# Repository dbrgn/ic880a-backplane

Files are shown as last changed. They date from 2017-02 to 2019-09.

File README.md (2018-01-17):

# iC880A + Raspberry Pi Backplane

*Buy this board at [shop.coredump.ch](https://shop.coredump.ch/product/ic880a-lorawan-gateway-backplane/)!*

This is a backplane to connect an iC880A-SPI concentrator board to a Raspberry
Pi. It is inspired by the [iC880A backplane by
@gonzalocasas](https://github.com/gonzalocasas/ic880a-backplane), but aims to
give you the following additional features:

Power

- Screw terminal and footprint for MP1584 step-down regulator module (6.7-28V)
- Screw terminal for direct power input/output (5V)
- Protection diode and resettable polyfuse against high voltage spikes
- Protection against reverse polarity power input

Headers

- Full access to Raspberry Pi GPIO header
- Pin header for serial communication (RX/TX)
- 2 Pin headers for I²C based sensors (SDA/SCL/GND/3.3V/5V)

Sensors

- A [SHT21](https://sensirion.com/sht21/) temperature/humidity sensor
- An MCP3425 16-bit ADC to measure RPi supply voltage

Other

- Pin header with flyback diode for 5V fan (5V/GND)
- General purpose button connected to GPIO pin (e.g. for controlled Raspi
  shutdown)
- Three general purpose SMD LEDs (Note: Only usable from Raspi versions
  with 40-pin GPIO header)
- Mounting holes for Raspberry Pi B+ / 2B / 3B / Zero

## PCB

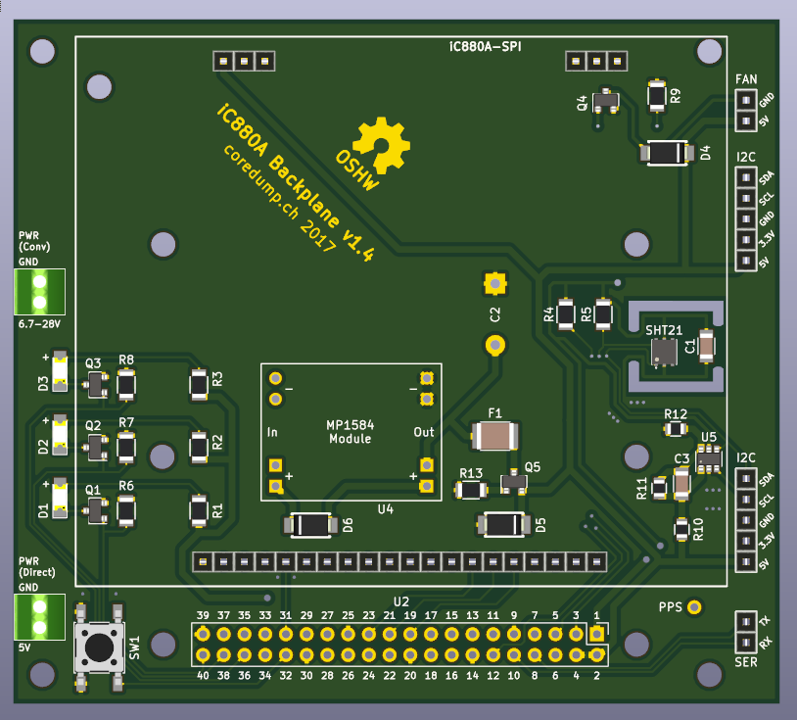
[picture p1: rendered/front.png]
Rendered


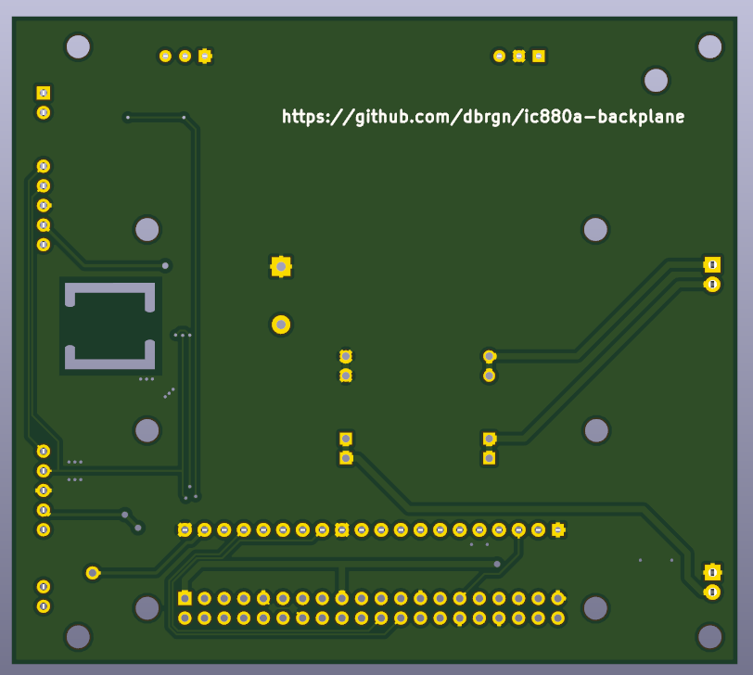
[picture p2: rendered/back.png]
Rendered


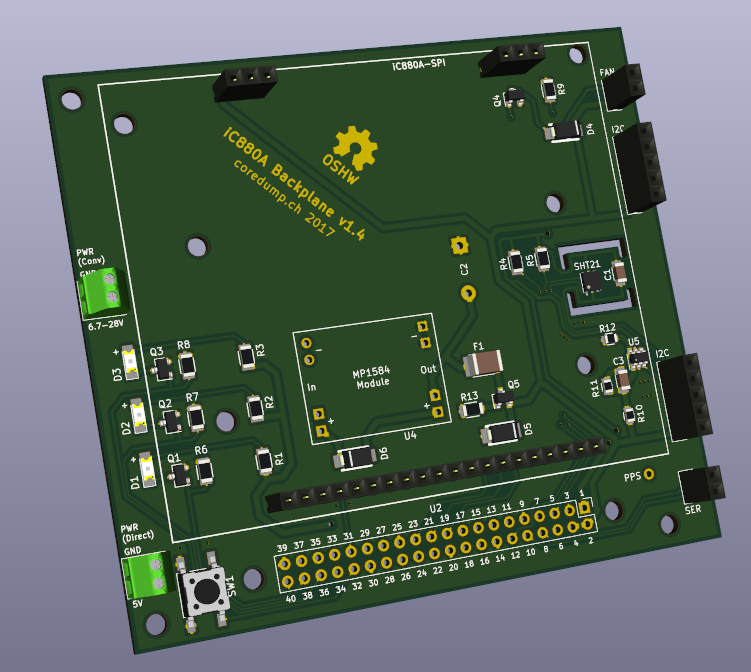
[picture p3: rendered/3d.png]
Rendered


## Schematics

See [schematics-v1.4.pdf](schematics-v1.4.pdf).

## Development

This PCB was created using KiCad 4.

Make sure that you clone all submodules:

    git submodule init
    git submodule update

## License

© 2017–2018 Danilo Bargen. Licensed under the TAPR Open Hardware License (www.tapr.org/OHL).

If you make any modification to this board, it would be great if you could let
me know at mail@dbrgn.ch.

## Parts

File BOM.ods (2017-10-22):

BOM as of v1.4, 2017-10-22
 | Description | Count | Manufacturer | Value | Case | digikey.com | mikroshop.ch
Main | iC880A-SPI | 1 | IMST
 | Raspberry Pi | 1
 | Backplane PCB | 1
 | 2 Pin Screw Terminal Block 2.54mm | 1 |  |  |  |  | 9_410
 | Pin Header 1x2 | 2
 | Pin Header 1x3 | 2
 | Pin Header 1x5 | 2
 | Pin Header 1x20 | 1
 | Resettable Fuse | 1 | Bourns |  |  | MF-MSMF250/16X-2CT-ND
 | Protection Diode | 1 | Vishay |  |  | SMBJ5.0A-E3/5BGICT-ND
 | Protection MOSFET P-Channel | 1 | Diodes Incorporated |  |  | DMG2305UX-13DICT-ND
 | Resistor | 1 | Yageo | 10kΩ | 1206 | 311-10KERCT-ND | 1_47_173
LEDs | MOSFET N-Channel | 3 | Toshiba |  | SOT-23 | SSM3K329RLFCT-ND
 | Resistor | 3 | Yageo | 10kΩ | 1206 | 311-10KERCT-ND | 1_47_173
 | SMD LED R | 1 |  | 2-2.2V | 1206 |  | 7_428
 | SMD LED Y | 1 |  | 2-2.2V | 1206 |  | 7_113
 | SMD LED B | 1 |  | 3-3.2V | 1206 |  | 7_429
 | Resistor R/Y | 2 | Yageo | 82Ω | 1206 | 311-82ERCT-ND | 1_47_142
 | Resistor B | 1 | Yageo | 22Ω | 1206 | 311-22ERCT-ND | 1_47_133
Sensor | SHT21 Sensor | 1 | Sensirion |  | DNT | 1649-1005-1-ND
 | Capacitor | 1 | Samsung or Yageo | 100nF | 1206 | 1276-1017-1-ND | 2_494
 | Resistor | 2 | Yageo | 10kΩ | 1206 | 311-10KERCT-ND | 1_47_173
Regulator | MP1584 Step-Down Module | 1 |  |  |  |  | 10_1124
 | 2 Pin Screw Terminal Block 2.54mm | 1 |  |  |  |  | 9_410
Fan | MOSFET N-Channel | 1 | Toshiba |  | SOT-23 | SSM3K329RLFCT-ND
 | Schottky Diode | 1 | Vishay |  | DO214-AC |  | 8_896
 | Resistor | 1 | Yageo | 10kΩ | 1206 |  | 1_47_173
ADC | MCP3425 | 1 | Microchip |  |  | MCP3425A0T-E/CHCT-ND
 | Resistor | 1 | Yageo | 470Ω | 805 | 311-470CRCT-ND
 | Resistor | 1 | Yageo | 3.6kΩ | 805 | 311-3.60KCRCT-ND
 | Resistor | 1 | Yageo | 6.8kΩ | 805 | 311-6.80KCRCT-ND
 | Capacitor | 1 | Samsung or Yageo | 100nF | 1206 | 1276-1017-1-ND | 2_494

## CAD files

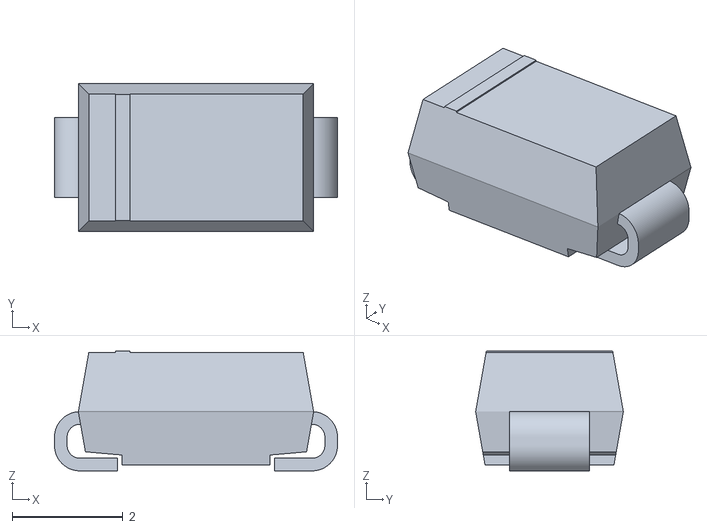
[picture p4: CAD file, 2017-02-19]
DO-214.3d/AB2_DO-214AC_WINGS3D.stl
5.11 x 2.66 x 2.16

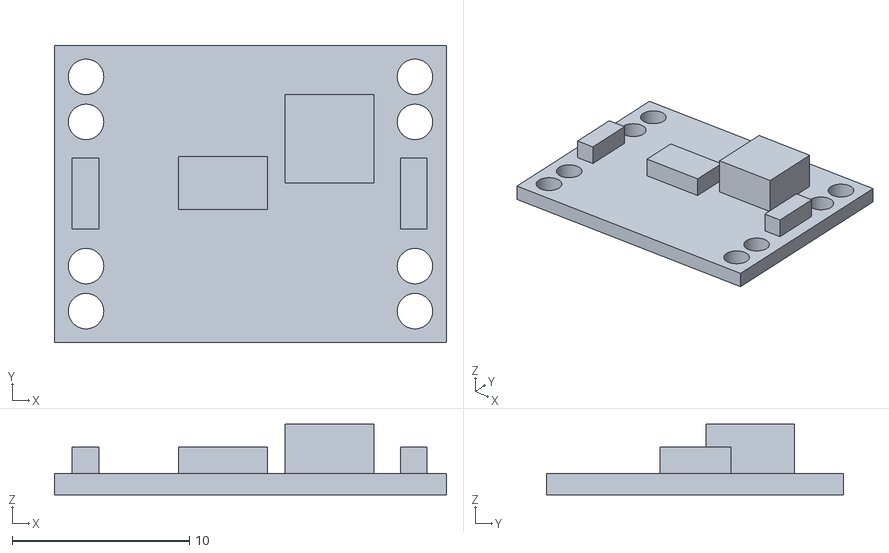
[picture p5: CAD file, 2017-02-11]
mp1584_module.stl
22.1 x 16.8 x 4.00

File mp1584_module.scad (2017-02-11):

$fn = 50;

w = 22.098;
h = 16.764;

module pin() {
    cylinder(h=2, r=1);
}

module pcb() {
    difference() {
        cube([22.098, 16.764, 1.2]);
        
        translate([1.778, 1.778]) pin();
        translate([w-1.778, 1.778]) pin();
        translate([w-1.778, h-1.778]) pin();
        translate([1.778, h-1.778]) pin();
        
        translate([1.778, 4.318]) pin();
        translate([w-1.778, 4.318]) pin();
        translate([w-1.778, h-4.318]) pin();
        translate([1.778, h-4.318]) pin();
    }
}

module parts() {
    translate([13, 9, 0])
        cube([5, 5, 2.8]);
    translate([7, 7.5, 0])
        cube([5, 3, 1.5]);
    translate([1, 6.4, 0])
        cube([1.5, 4, 1.5]);
    translate([19.5, 6.4, 0])
        cube([1.5, 4, 1.5]);
}

pcb();
translate([0, 0, 1.2]) parts();

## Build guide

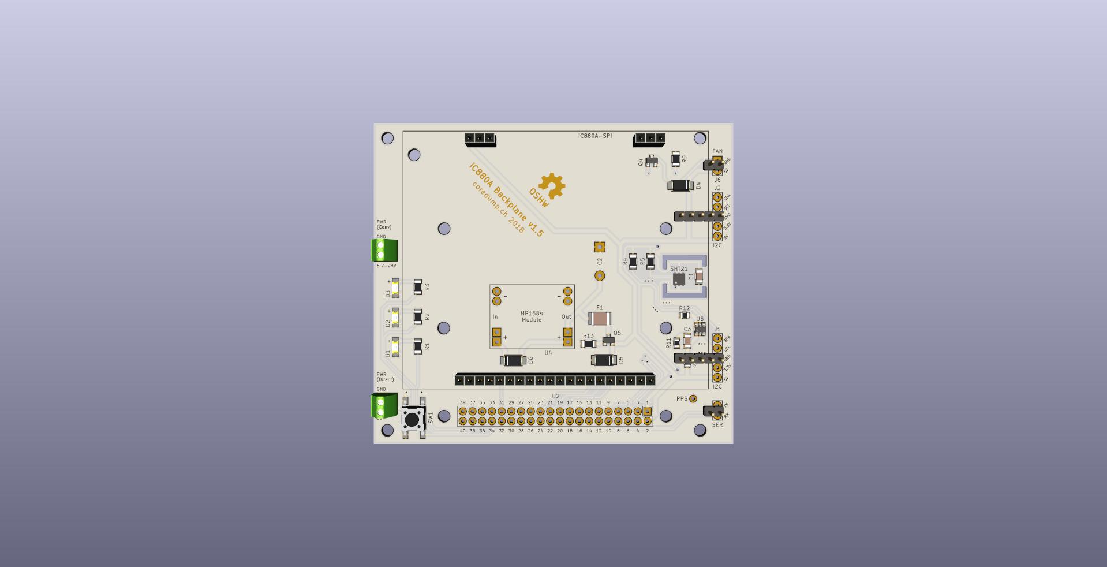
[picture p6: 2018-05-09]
backplane-assembly.jpg

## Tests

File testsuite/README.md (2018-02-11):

Testing setup moved to [dbrgn/ic880a-backplane-testimage](https://github.com/dbrgn/ic880a-backplane-testimage).

The Python test scripts are located [here](https://github.com/dbrgn/ic880a-backplane-testimage/tree/master/ic880a-backplane/rootfs-overlay/root).

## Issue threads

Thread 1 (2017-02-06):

Remove GPS header

dbrgn, 2017-02-06:
https://www.thethingsnetwork.org/forum/t/advantage-of-connecting-gps-to-gateway/1111/2

Looks like the GPS RX/TX pins are only needed to pass data from the onboard GPS to the host.

Since the board doesn't currently include GPS (to my knowledge), that is not really useful.

And since I don't know how to connect a GPS to the PPS input, it's probably better to leave the header away instead of creating a half-baked solution.

Closed 2017-02-06.

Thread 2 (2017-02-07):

More mounting holes?

dbrgn, 2017-02-07:
Is the Raspberry Pi Zero different?

I won't add the old model B mounting holes since the GPIO header isn't compatible anyways.

Closed 2017-02-08.

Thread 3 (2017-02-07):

Fix silkscreen

dbrgn, 2017-02-07:
Make sure silkscreen labels are correct everywhere.

Closed 2017-02-08.

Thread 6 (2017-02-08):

Add step-down voltage regulator

dbrgn, 2017-02-08:
Something around the range of 5-12v should be fine. Good in combination with PoE kits.

Maybe add capacitor at 5V output to stabilize voltage.

Closed 2017-02-12.

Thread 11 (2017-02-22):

Fix MOSFETs

dbrgn, 2017-02-22:
First order has wrong pin order on MOSFETs.

It's still perfectly fine though when not populating the LEDs and/or the fan. But it should be fixed for the next order. Alternative would be rotating the MOSFETs and jumper wire.

dbrgn, 2017-02-22:
https://www.digikey.com/product-detail/en/toshiba-semiconductor-and-storage/SSM3K339R,LF/SSM3K339RLFCT-ND/4781038

Closed 2017-03-14.

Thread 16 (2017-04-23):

Make sensor cutouts easier to manufacture

dbrgn, 2017-04-23:
Instead of 90° angles, use a small rounded corner so that it can be properly milled.

dbrgn, 2017-10-10:
Since it always worked out nicely so far, I don't see the need to change it.

Closed 2017-10-10.

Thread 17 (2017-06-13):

Use self locking footprints for pin headers

dbrgn, 2017-06-13:
https://www.sparkfun.com/tutorials/114

dbrgn, 2018-01-17:
Didn't work out well.

Closed 2018-01-17.

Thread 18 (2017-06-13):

Improve button footprint

dbrgn, 2017-06-13:
The pin spacing is a bit too large.

Closed 2017-06-16.

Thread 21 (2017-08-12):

Hole for attaching iC880A to board

dbrgn, 2017-08-12:
For better mechanical stability.

Closed 2017-10-10.

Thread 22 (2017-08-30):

Get rid of D5

dbrgn, 2017-08-30:
The diode is not necessary when choosing the P-FET correctly:

https://www.youtube.com/watch?v=IrB-FPcv1Dc

ubruhin, 2017-08-30:
D5 does *not* have the same functionality as the diode shown in the video. Our diode is for transient voltage suppression, not for Vgs overvoltage protection.

dbrgn, 2017-08-30:
Oops, you're right. Thanks for noting, it's a bit late :smile:

Closed 2017-08-30.

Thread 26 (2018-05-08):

Move Vin connectors out of the way

dbrgn, 2018-05-08:
It should be impossible to short with the USB/Ethernet connectors.

Closed 2018-05-10.

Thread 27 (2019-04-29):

Raspberry Pi 3B+

Wlanfr3ak, 2019-04-29:
Is it compatible to the Raspberry Pi 3B+ ?

dbrgn, 2019-04-30:
It seems that the pinout didn't change, so yes, it should be compatible :slightly_smiling_face: I didn't test it though.

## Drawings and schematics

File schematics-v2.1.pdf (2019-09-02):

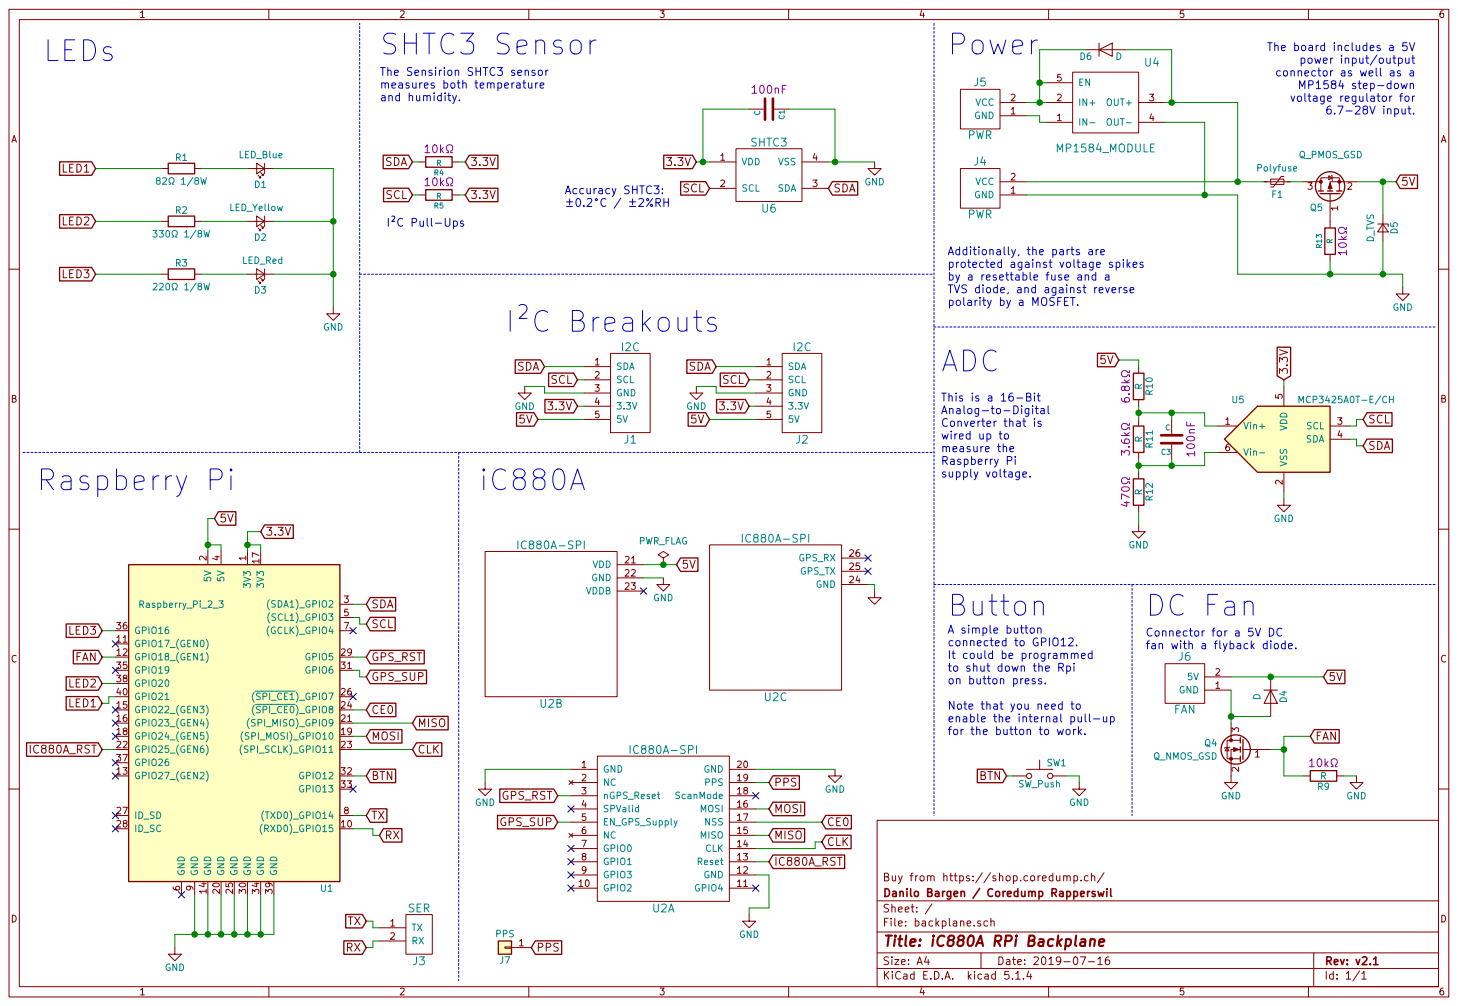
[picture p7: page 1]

power input/output connector as well as a MP1584 step-down

5 Vin- 6 U5 MCP3425A0T-E/CH GND GND GND

Additionally, the parts are
protected against voltage spikes
by a resettable fuse and a
TVS diode, and against reverse
polarity by a MOSFET.
ADC

This is a 16-Bit Analog-to-Digital

Converter that is
wired up to measure the Raspberry Pi

9U1 Raspberry_Pi_2_3 GND 1 GPIO2 10 GPIO4 11 GND 12 Reset 13 CLK 14 MISO 15 MOSI 16 NSS 17 ScanMode 18 PPS 19 NC 2 GND 20

A simple button
connected to GPIO12.
It could be programmed
to shut down the Rpi
on button press.

Connector for a 5V DC
fan with a flyback diode.

Note that you need to
enable the internal pull-up
for the button to work.

Buy from https://shop.coredump.ch/
File: backplane.sch Sheet: / Danilo Bargen / Coredump Rapperswil

Id: 1/1 Title: iC880A RPi Backplane

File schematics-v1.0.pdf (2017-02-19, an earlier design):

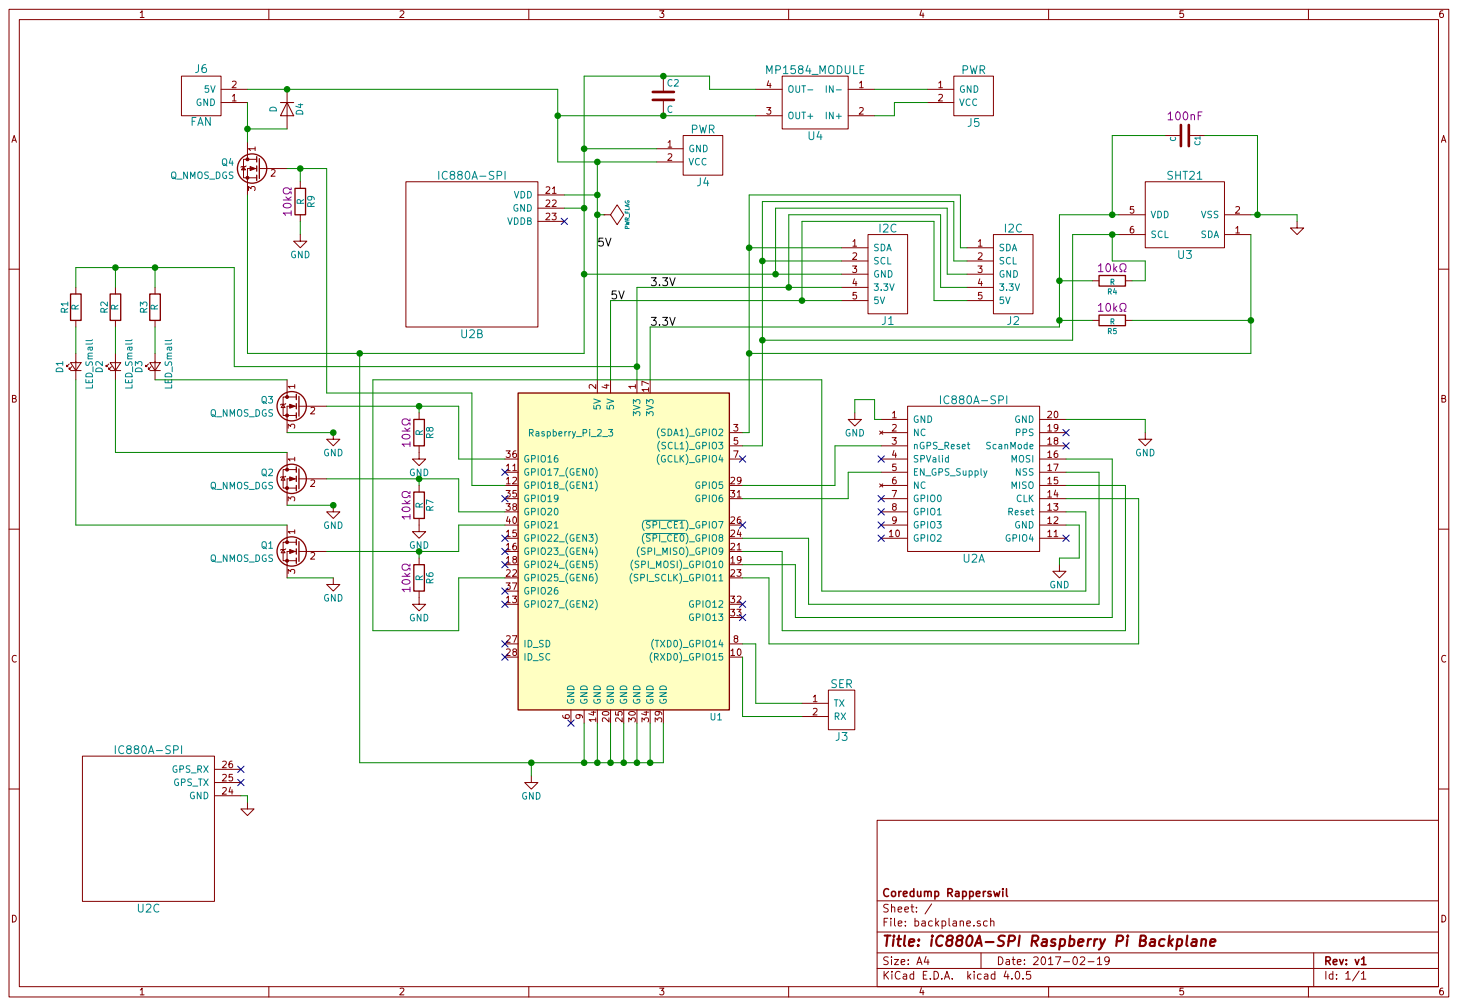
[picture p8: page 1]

3 Q1 Q_NMOS_DGS GND GND GND GND GND GND GND

File: backplane.sch Sheet: / Coredump Rapperswil

Id: 1/1 Title: iC880A-SPI Raspberry Pi Backplane

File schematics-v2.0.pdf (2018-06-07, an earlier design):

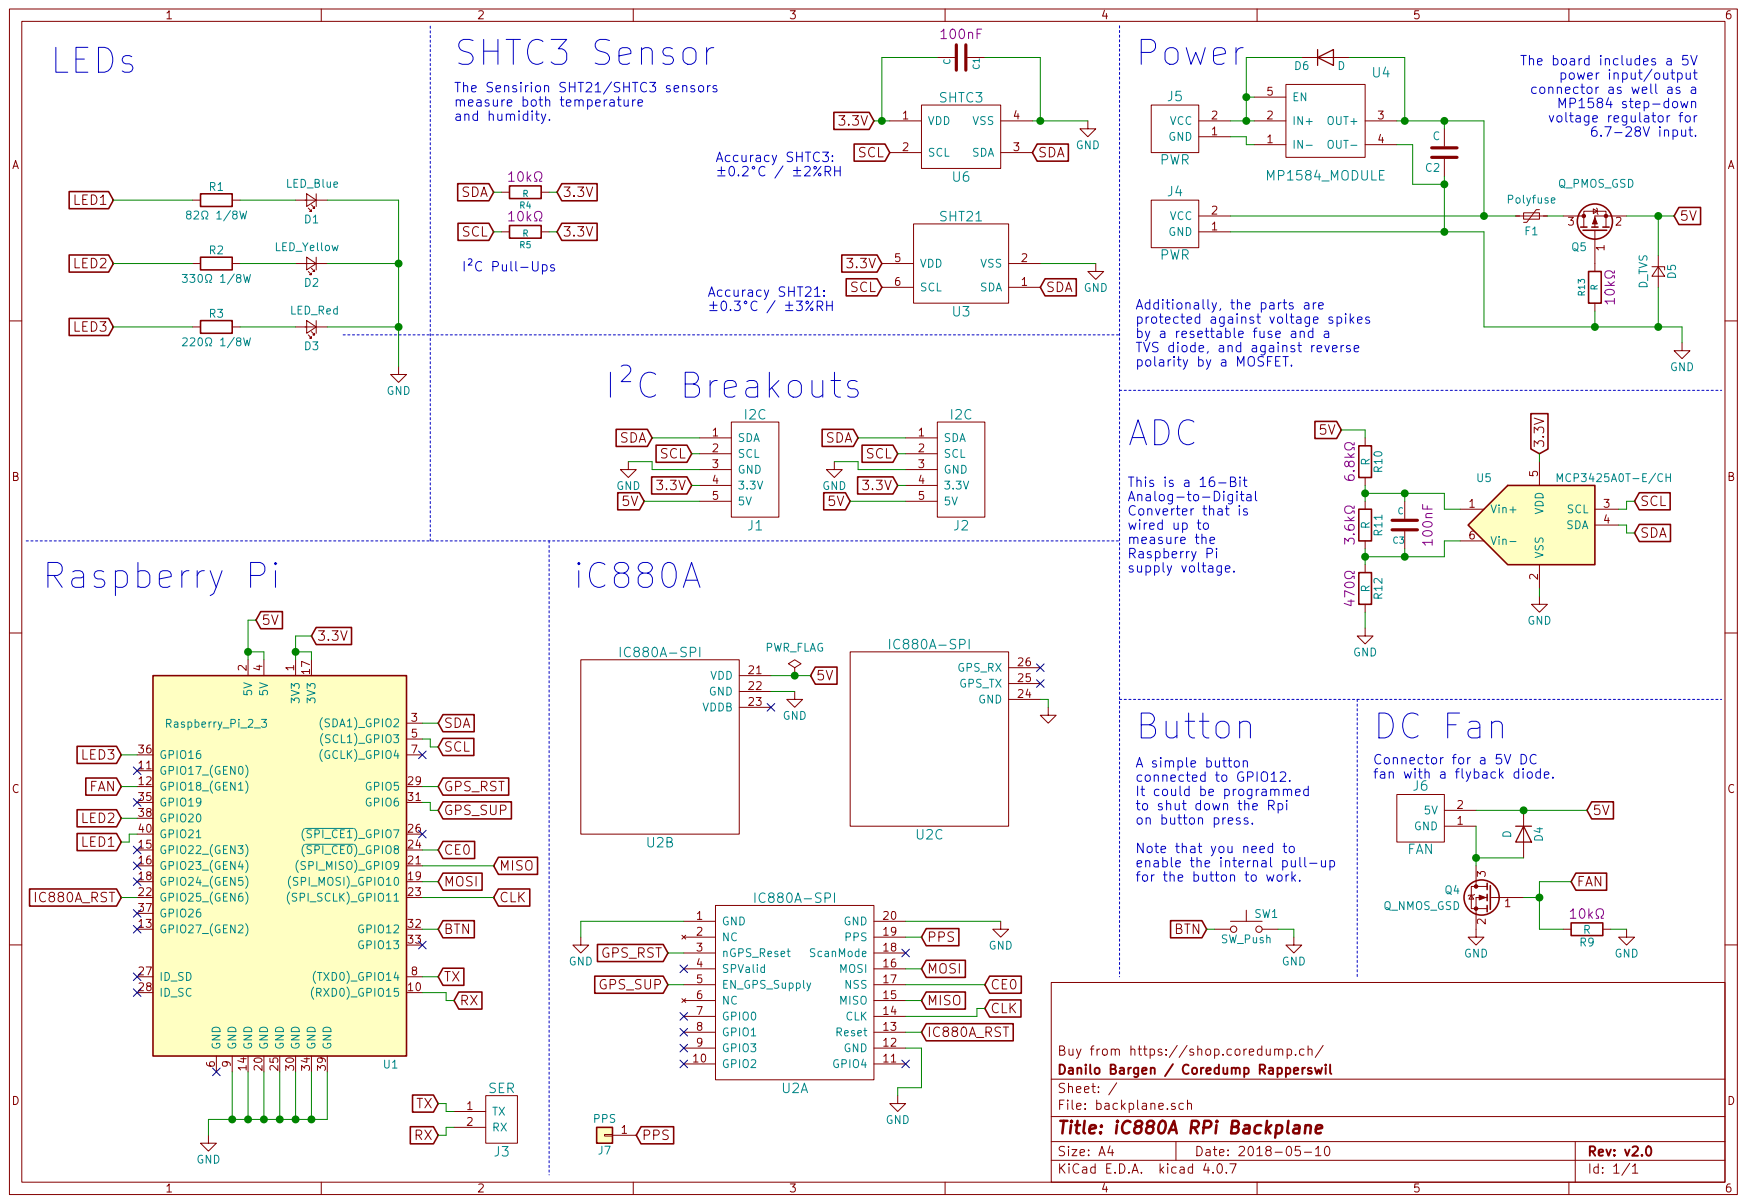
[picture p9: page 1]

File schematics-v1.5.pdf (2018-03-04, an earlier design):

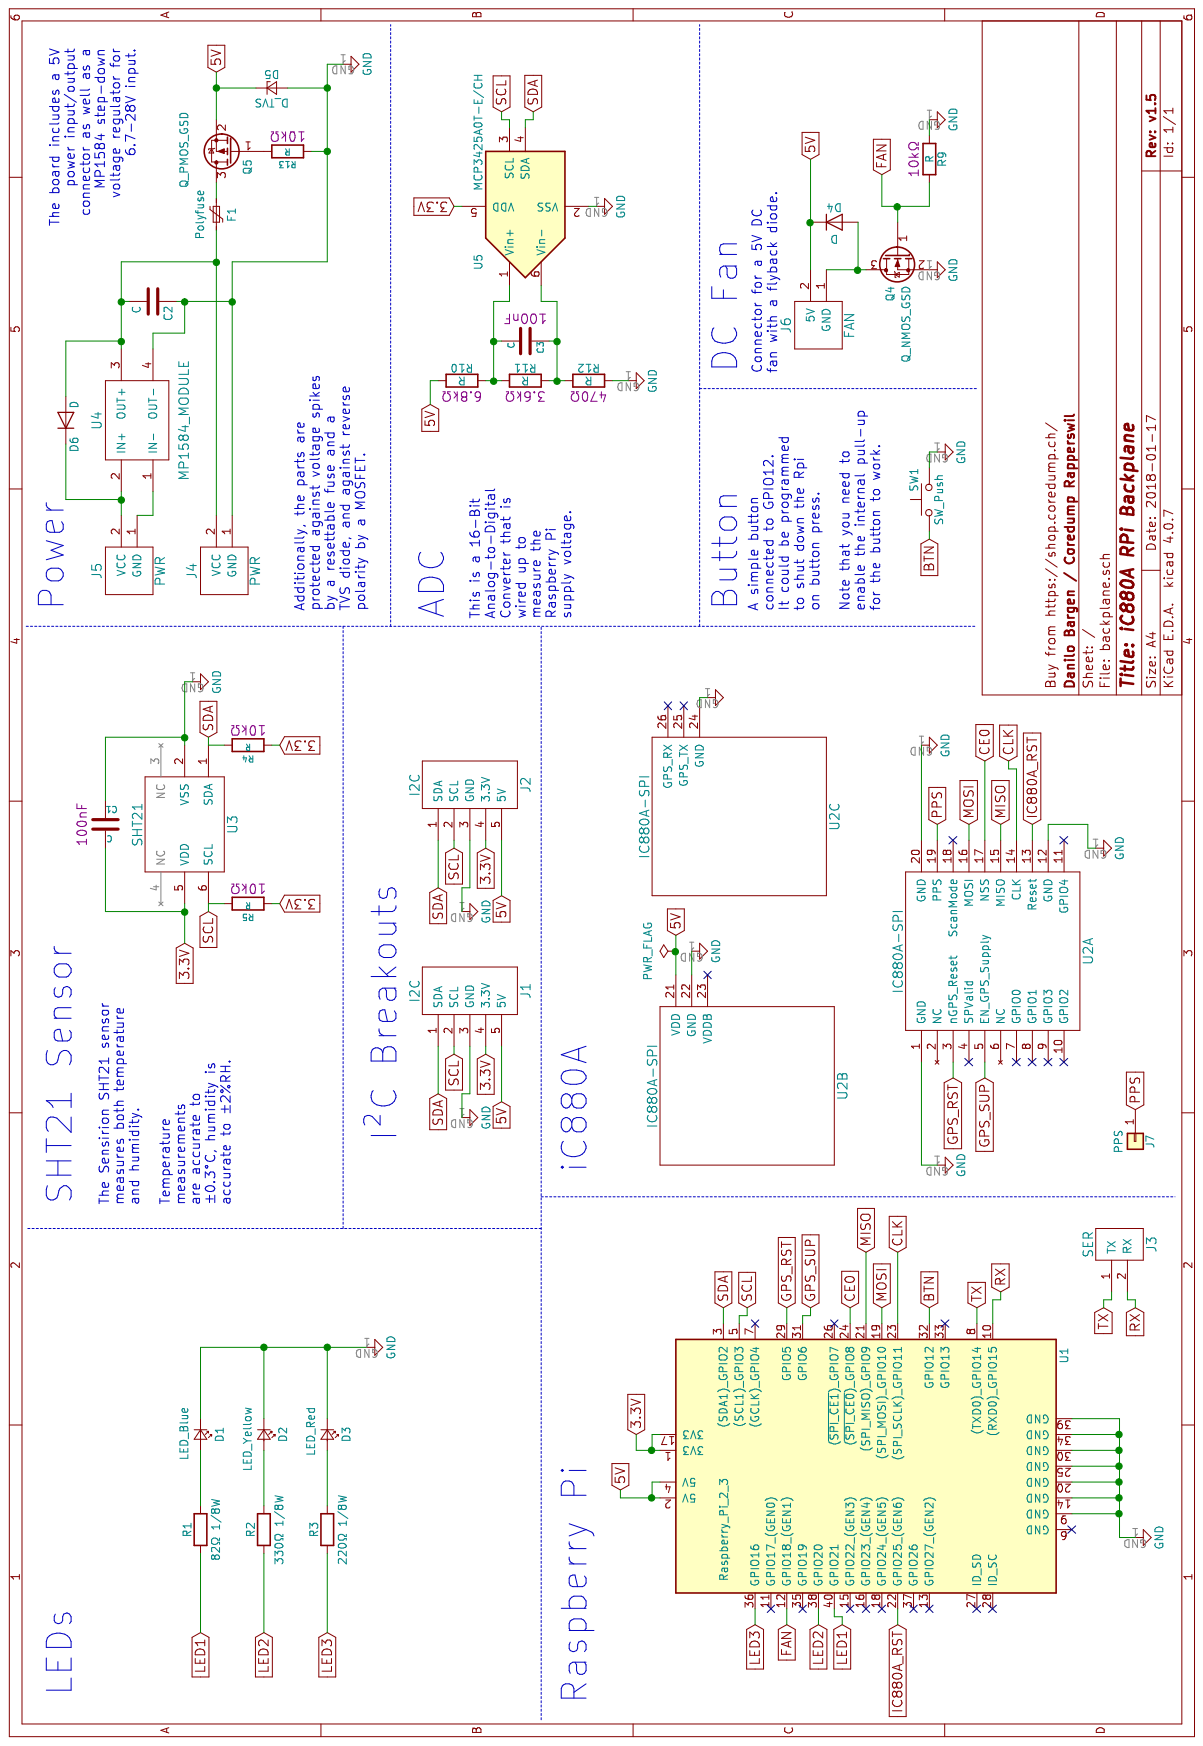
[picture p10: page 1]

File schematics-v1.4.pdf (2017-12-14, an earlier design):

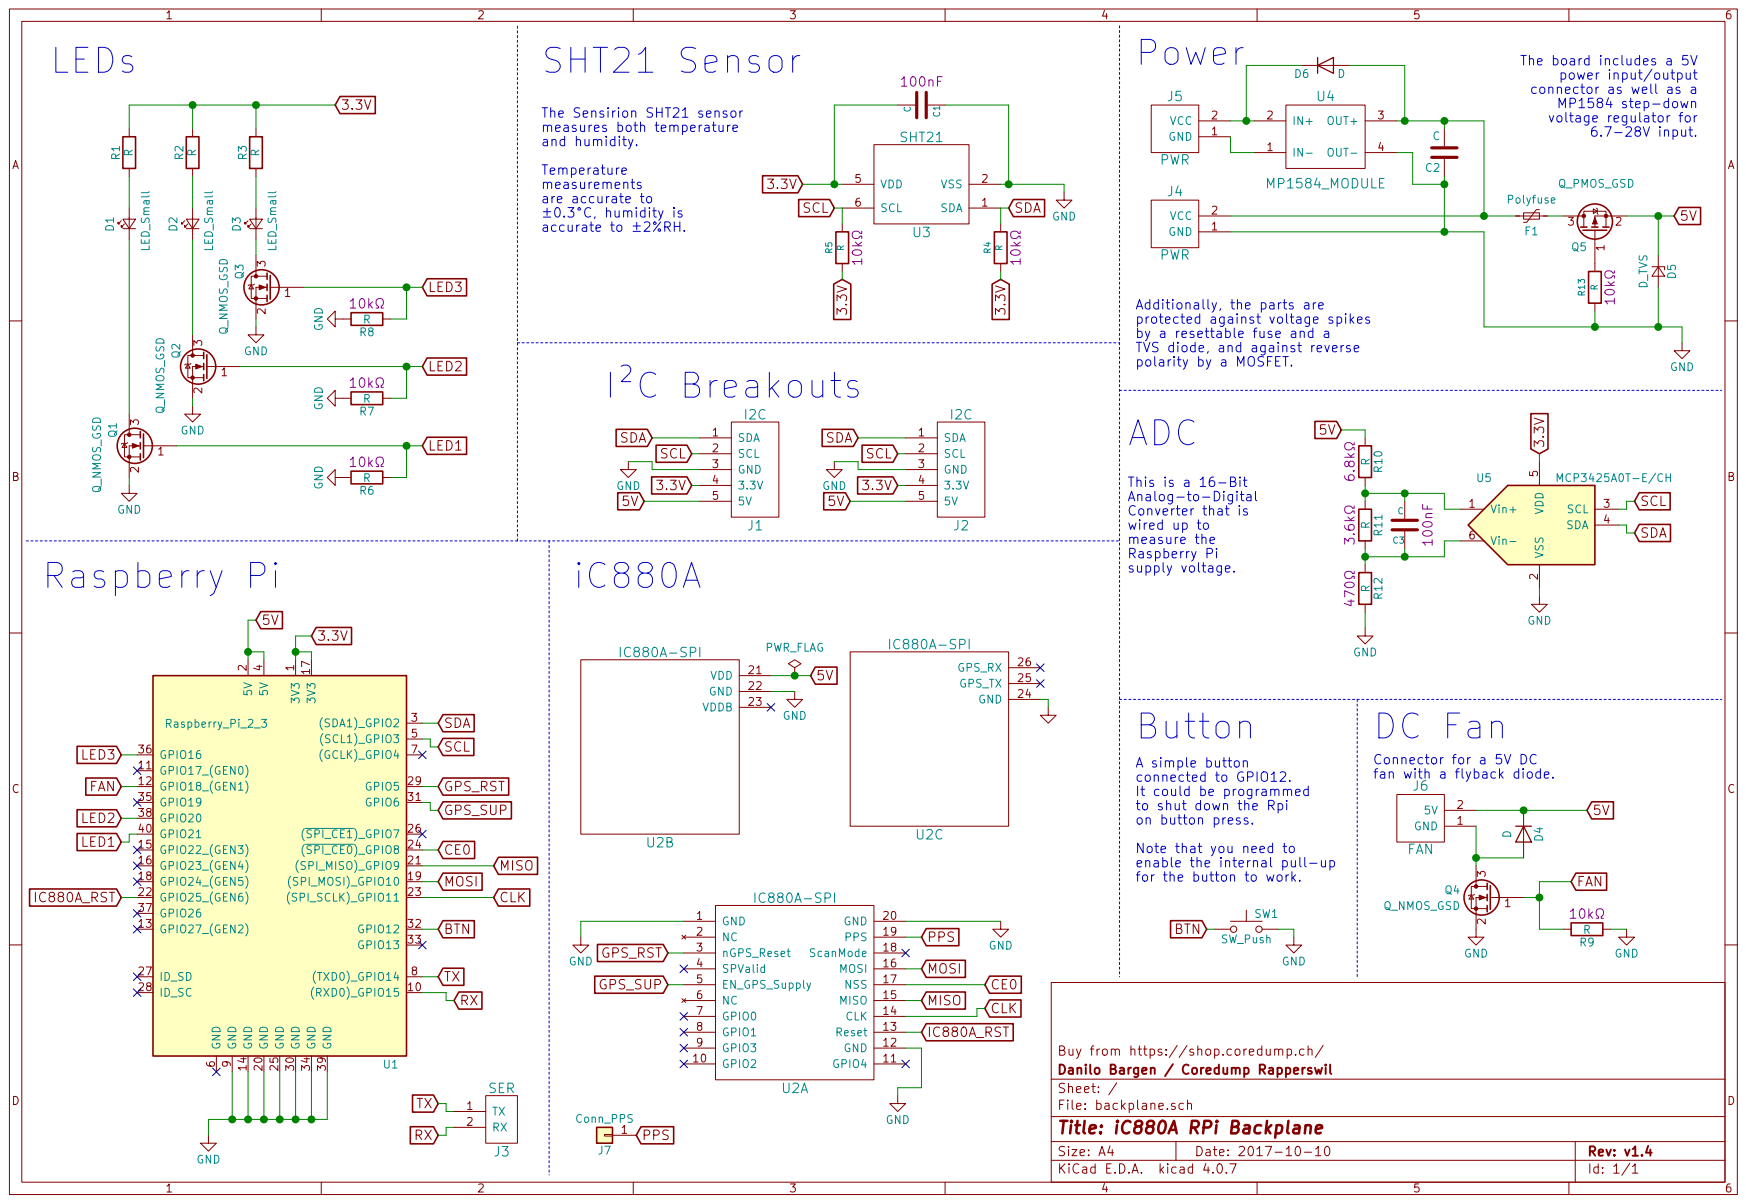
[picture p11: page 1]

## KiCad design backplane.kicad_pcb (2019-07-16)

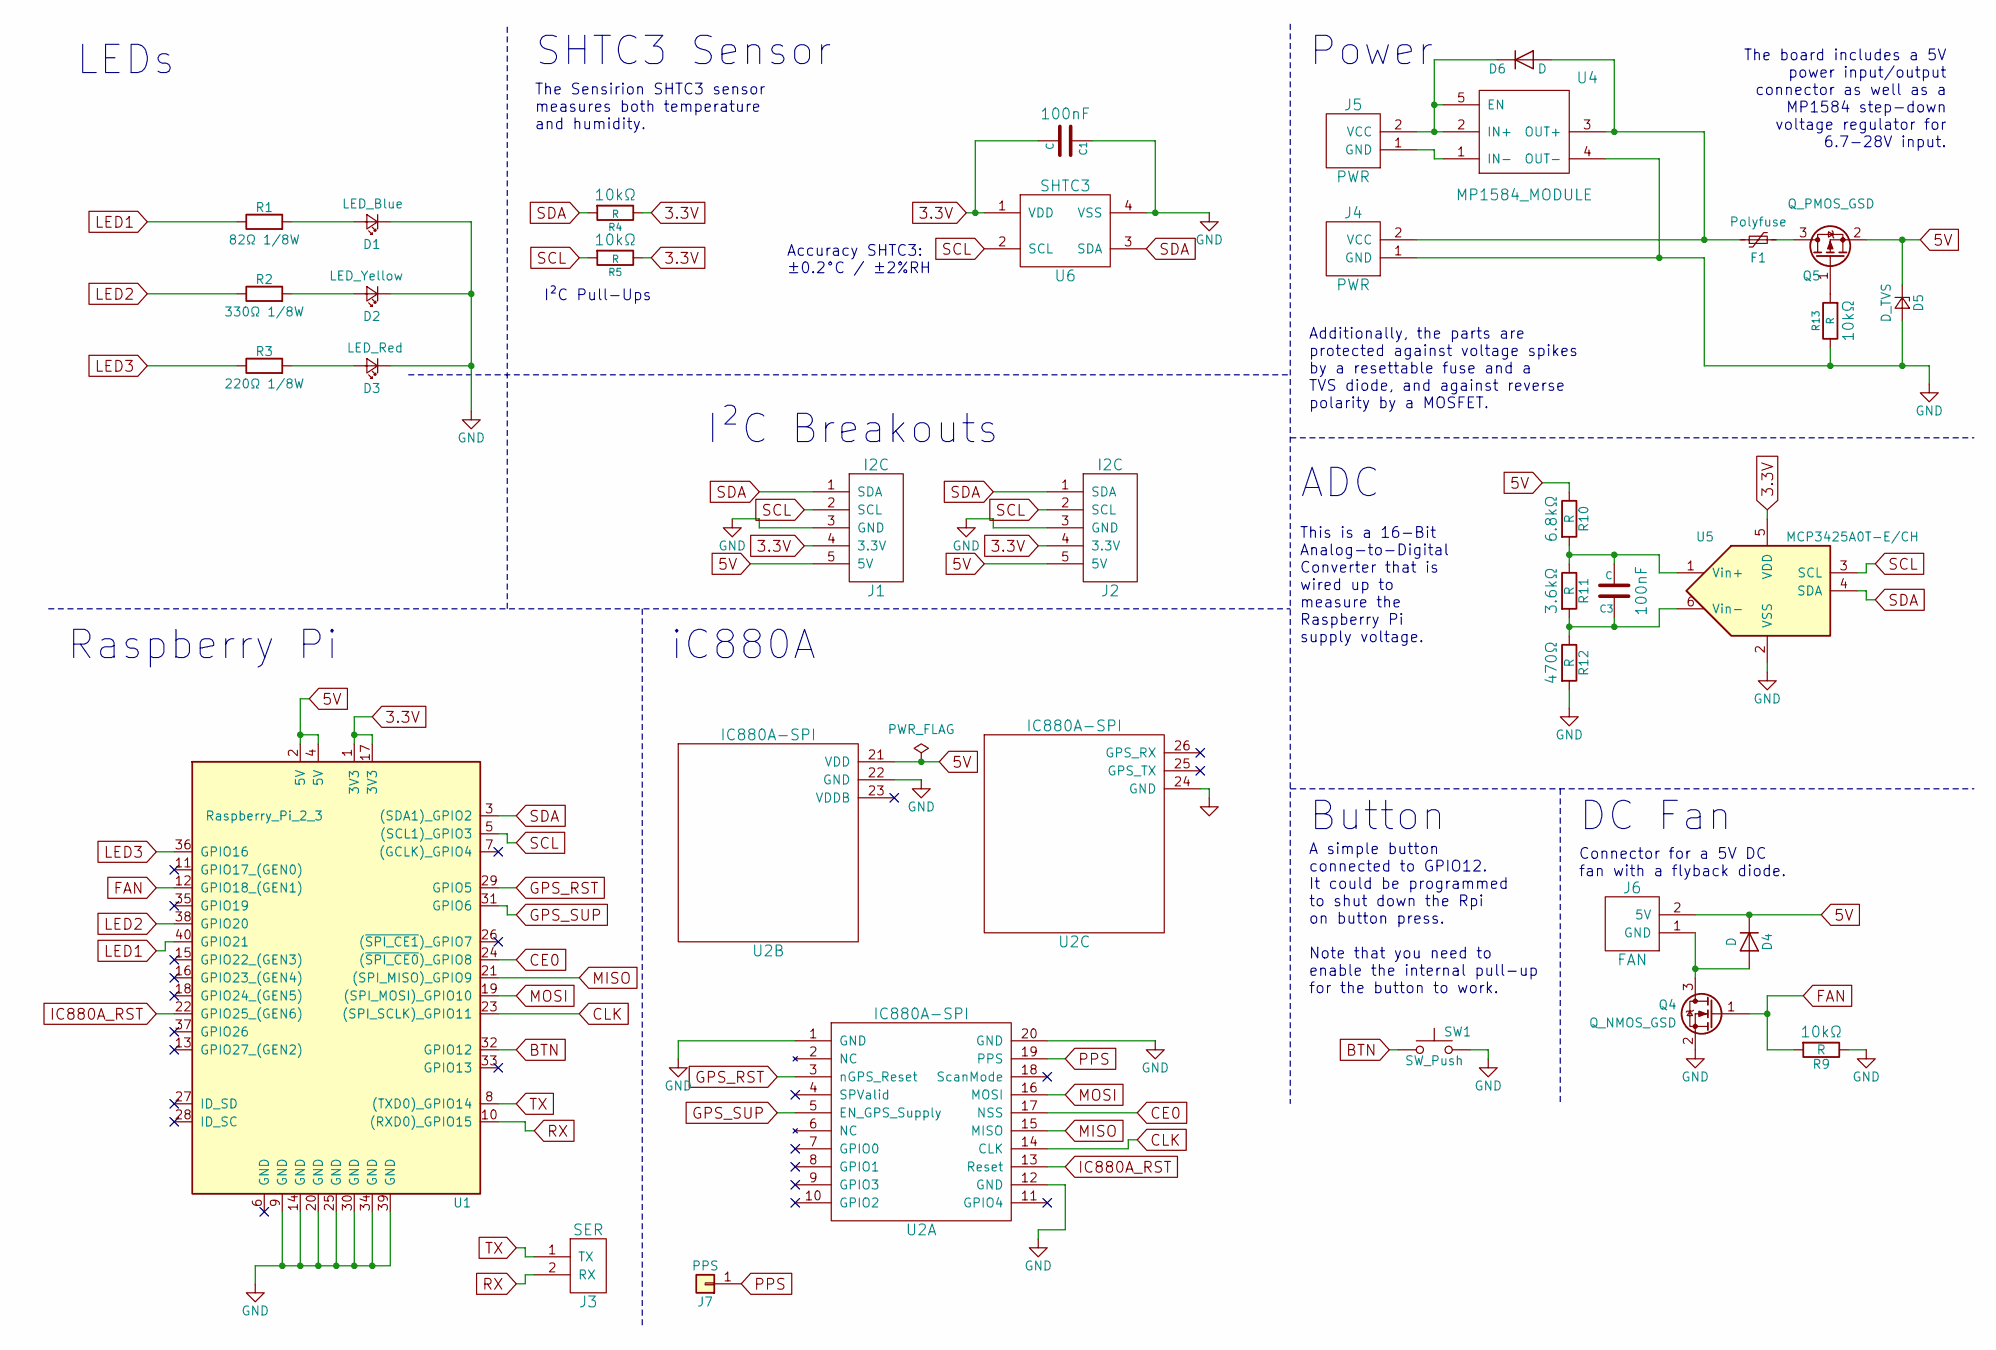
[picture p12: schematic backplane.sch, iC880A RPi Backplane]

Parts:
C1, C3: C; C_1206
D1: LED_Blue; LED_1206
D2: LED_Yellow; LED_1206
D3: LED_Red; LED_1206
D4, D6: D; DO-214AC
D5: D_TVS; DO-214AA; Digikey SMBJ5.0A-E3/5BGICT-ND
F1: Polyfuse; C_1812; Digikey MF-MSMF250/16X-2CT-ND
J1, J2: I2C; header_1x5_unmarked
J3: SER; header_1x2_unmarked
J4, J5: PWR; TerminalBlock_Pheonix_MPT-2.54mm_2pol
J6: FAN; header_1x2_marked
J7: PPS; header_1x1_unmarked
Q4: Q_NMOS_GSD; SOT-23
Q5: Q_PMOS_GSD; SOT-23
R1: 82Ω 1/8W; R_1206
R2: 330Ω 1/8W; R_1206
R3: 220Ω 1/8W; R_1206
R4, R5, R9, R13: R; R_1206
R10, R11, R12: R; R_0805
SW1: SW_Push; SW_Mikroshop
U1: Raspberry_Pi_2_3; Pin_Header_Straight_2x20_Pitch2.54mm
U2: IC880A-SPI
U4: MP1584_MODULE; MP1584_MODULE_ZVEPOWER
U5: MCP3425A0T-E/CH; SOT-23-6
U6: SHTC3; SHTC1

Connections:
3.3V: C1.2, J1.4 (3.3V), J2.4 (3.3V), R4.1, R5.1, U1.1 (3V3), U1.17 (3V3), U5.5 (VDD), U6.1 (VDD)
5V: D4.1 (K), D5.1 (K), J1.5 (5V), J2.5 (5V), J6.2 (5V), Q5.2 (S), R10.1, U1.2 (5V), U1.4 (5V), U2.21 (VDD)
BTN: SW1.1, U1.32 (GPIO12)
CE0: U1.24 ((~SPI_CE0~)_GPIO8), U2.17 (NSS)
CLK: U1.23 ((SPI_SCLK)_GPIO11), U2.14 (CLK)
FAN: Q4.1 (G), R9.2, U1.12 (GPIO18_(GEN1))
GND: C1.1, D1.1 (K), D2.1 (K), D3.1 (K), D5.2 (A), J1.3 (GND), J2.3 (GND), J4.1 (GND), Q4.2 (S), R9.1, R12.2, R13.1, SW1.2, U1.9 (GND), U1.14 (GND), U1.20 (GND), U1.25 (GND), U1.30 (GND), U1.34 (GND), U1.39 (GND), U2.1 (GND), U2.12 (GND), U2.20 (GND), U2.22 (GND), U2.24 (GND), U4.4 (OUT-), U5.2 (VSS), U6.4 (VSS)
GPS_RST: U1.29 (GPIO5), U2.3 (nGPS_Reset)
GPS_SUP: U1.31 (GPIO6), U2.5 (EN_GPS_Supply)
IC880A_RST: U1.22 (GPIO25_(GEN6)), U2.13 (Reset)
LED1: R1.1, U1.40 (GPIO21)
LED2: R2.1, U1.38 (GPIO20)
LED3: R3.1, U1.36 (GPIO16)
MISO: U1.21 ((SPI_MISO)_GPIO9), U2.15 (MISO)
MOSI: U1.19 ((SPI_MOSI)_GPIO10), U2.16 (MOSI)
unnamed: D6.2 (A), F1.1, J4.2 (VCC), U4.3 (OUT+)
unnamed: C3.1, R11.2, R12.1, U5.6 (Vin-)
unnamed: C3.2, R10.2, R11.1, U5.1 (Vin+)
unnamed: D1.2 (A), R1.2
unnamed: D2.2 (A), R2.2
unnamed: D3.2 (A), R3.2
unnamed: D4.2 (A), J6.1 (GND), Q4.3 (D)
unnamed: D6.1 (K), J5.2 (VCC), U4.2 (IN+), U4.5 (EN)
unnamed: F1.2, Q5.3 (D)
unnamed: J5.1 (GND), U4.1 (IN-)
unnamed: Q5.1 (G), R13.2
PPS: J7.1, U2.19 (PPS)
RX: J3.2 (RX), U1.10 ((RXD0)_GPIO15)
SCL: J1.2 (SCL), J2.2 (SCL), R5.2, U1.5 ((SCL1)_GPIO3), U5.3 (SCL), U6.2 (SCL)
SDA: J1.1 (SDA), J2.1 (SDA), R4.2, U1.3 ((SDA1)_GPIO2), U5.4 (SDA), U6.3 (SDA)
TX: J3.1 (TX), U1.8 ((TXD0)_GPIO14)

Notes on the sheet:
Raspberry Pi
iC880A
LEDs
SHTC3 Sensor
I²C Breakouts
Power
ADC
DC Fan
Connector for a 5V DC fan with a flyback diode.
This is a 16-Bit Analog-to-Digital Converter that is wired up to measure the Raspberry Pi supply voltage.
The board includes a 5V power input/output connector as well as a MP1584 step-down voltage regulator for 6.7-28V input.
The Sensirion SHTC3 sensor measures both temperature and humidity.
Button
A simple button connected to GPIO12. It could be programmed to shut down the Rpi on button press. Note that you need to enable the internal pull-up for the button to work.
Additionally, the parts are protected against voltage spikes by a resettable fuse and a TVS diode, and against reverse polarity by a MOSFET.
Accuracy SHTC3: ±0.2°C / ±2%RH
I²C Pull-Ups

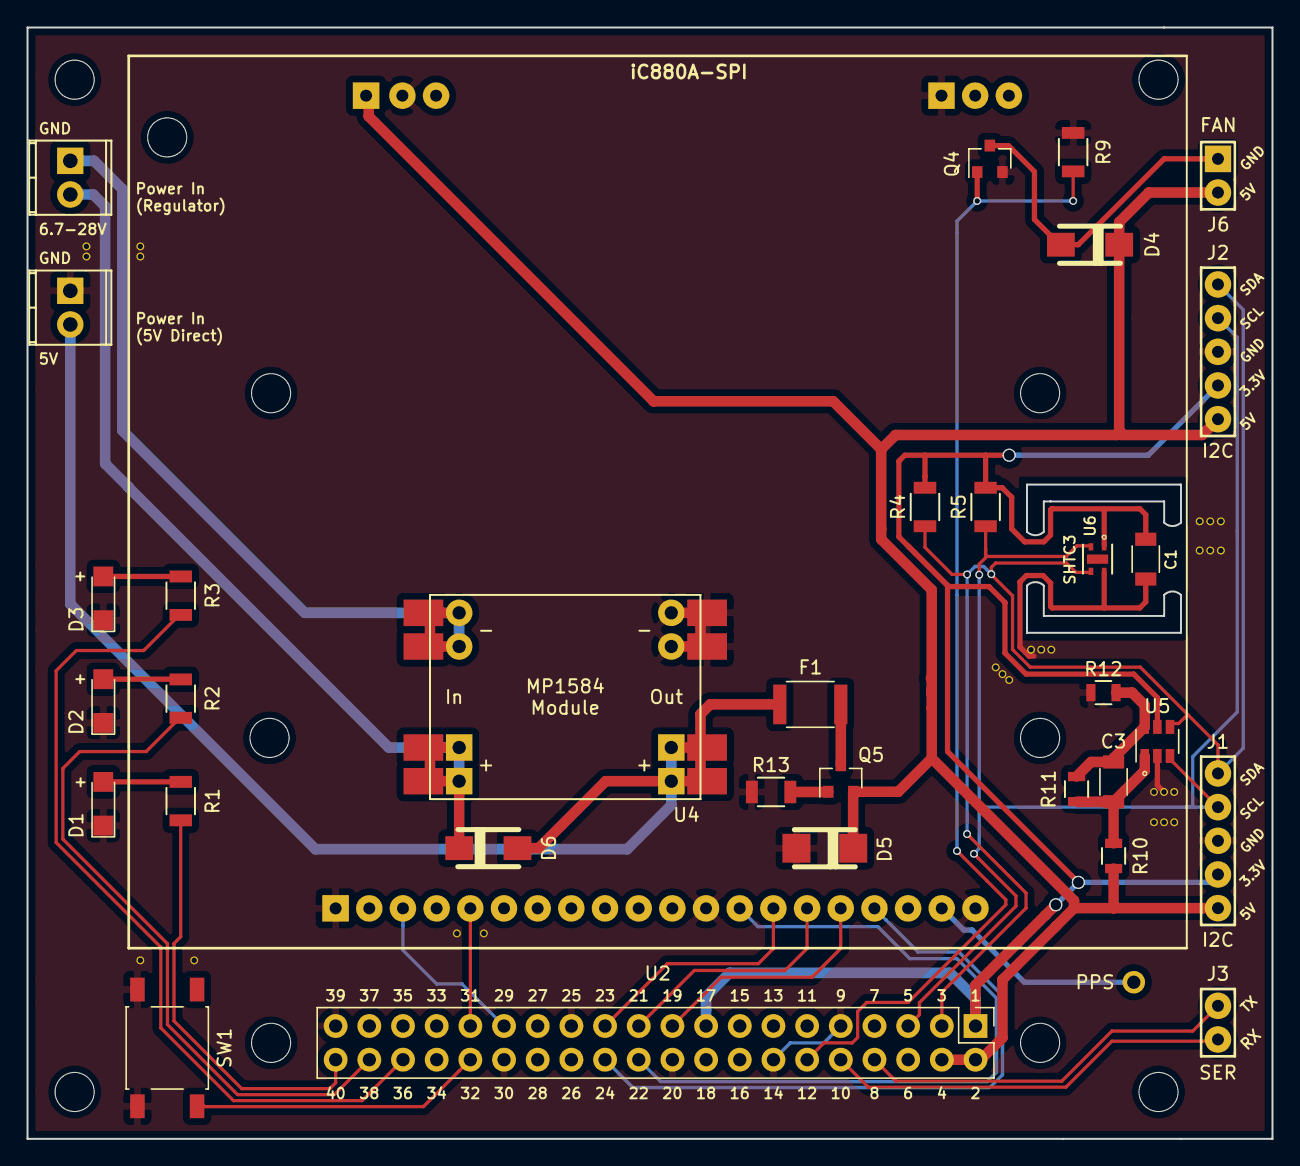
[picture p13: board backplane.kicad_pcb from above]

Board: 2 copper layers, 93.9 x 83.8 mm, 34 parts (0 on the bottom side), 31 nets.

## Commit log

2017-02-05 More ground connections and thicker power tracks
    [backplane.kicad_pcb, backplane.sch]
2017-02-05 Add text to PCB
    [backplane.kicad_pcb]
2017-02-06 Remove GPS header (fixes #1)
    [backplane.kicad_pcb, backplane.sch]
2017-02-06 Add SHT21 to schema
    [backplane.sch]
2017-02-07 Re-add OSHW logo
    [backplane.kicad_pcb]
2017-02-07 Add SHT21 sensor
    [backplane.kicad_pcb, backplane.sch]
2017-02-07 Add Raspberry Pi mounting holes
    [backplane.kicad_pcb]
2017-02-07 Nicer keepout area around sensor
    [backplane.kicad_pcb]
2017-02-08 Nicer labels
    [backplane.kicad_pcb]
2017-02-08 Raspberry Pi GPIO numbers
    [backplane.kicad_pcb]
2017-02-08 I2C pullups
    [backplane.kicad_pcb, backplane.sch]
2017-02-08 Add silkscreen label for iC880A-SPI
    [backplane.kicad_pcb]
2017-02-08 Move labels
    [backplane.kicad_pcb]
2017-02-08 More mounting holes
    Fixes #2
    [backplane.kicad_pcb]
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2017-02-08 Second I²C header and various improvements
    Fixes #5
    [backplane.kicad_pcb, backplane.sch]
2017-02-08 Add 3D stuff
    [backplane.kicad_pcb]
2017-02-09 Correct 3D models
    [backplane.kicad_pcb]
2017-02-10 Start adding fan connectors
    [backplane.sch]
2017-02-10 Add pins for DC fan
    [backplane.kicad_pcb, backplane.sch]
2017-02-10 Add schema
    [backplane.kicad_pcb]
2017-02-10 Switch PWM pin for fan
    [backplane.kicad_pcb, backplane.sch]
2017-02-11 Started BOM.csv
    [BOM.csv]
2017-02-11 Small changes
    [backplane.kicad_pcb]
2017-02-11 Add Github URL to back side
    [backplane.kicad_pcb]
2017-02-11 Start integrating MP1584 dc converter board
    [BOM.csv, backplane.kicad_pcb, backplane.sch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]
2017-02-11 Use screw terminal for PWR
    [backplane.kicad_pcb, backplane.sch]
2017-02-11 Change annotation of LED MOSFETs
    [backplane.kicad_pcb, backplane.sch]
2017-02-11 Move LEDs closer together
    [backplane.kicad_pcb]
2017-02-12 Integrate step-down module
    [backplane.kicad_pcb, backplane.sch]
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2017-02-12 Add capacitor to schema
    [backplane.sch]
2017-02-13 Start working on variant
    [backplane.kicad_pcb, backplane.sch]
2017-02-18 More routing
    [backplane.kicad_pcb, backplane.sch]
2017-02-18 Finish routing
    [backplane.kicad_pcb]
2017-02-18 Fix capacitor footprint
    [backplane.kicad_pcb, backplane.sch]
2017-02-19 Simplify silkscreen text
    [backplane.kicad_pcb]
2017-02-19 Add pull-down to fan MOSFET
    [backplane.kicad_pcb, backplane.sch]
2017-02-19 Keepout zone behind sensor
    [backplane.kicad_pcb]
2017-02-19 Replace THT diode with SMD version
    [AB2_DO-214AC_WINGS3D.stl, backplane.kicad_pcb, backplane.sch]
2017-02-19 Update BOM
    [BOM.csv, BOM.ods]
2017-02-19 Improve silkscreen
    [backplane.kicad_pcb]
2017-02-19 Small change
    [backplane.kicad_pcb]
2017-03-14 Fix footprint of iC880A-SPI
    [backplane.kicad_pcb, backplane.sch]
2017-03-14 Fix NMOS parts in schema
    [backplane.sch]
2017-03-14 Fix MOSFET
    Unfortunately the traces now look a bit ugly because of non-ideal
    routing, but this way I can re-use the stencil.
    Fixes #11
    [backplane.kicad_pcb]
2017-03-14 Make tracks a bit nicer
    [backplane.kicad_pcb]
2017-04-10 Fix capacitor silkscreen
    [backplane.kicad_pcb]
2017-04-10 Larger holes (2.75 -> 2.95), fixes #12
    [backplane.kicad_pcb]
2017-04-14 Move regulator away from iC880A RF area
    Fixes #13
    [backplane.kicad_pcb]
2017-04-14 Start splitting up schema with labels
    [backplane.sch]
2017-04-14 Netlabel ALL THE THINGS
    [backplane.sch]
2017-04-14 Add ADC (refs #14)
    [backplane.sch]
2017-04-15 Assign footprints to ADC (refs #14)
    [backplane.sch]
2017-04-15 Add ADC to board (fixes #14)
    [backplane.kicad_pcb]
2017-04-15 Fix position of R4
    [backplane.kicad_pcb]
2017-04-15 Clean up schematics
    [backplane.sch]
2017-04-15 Update netlist
    [backplane.kicad_pcb, backplane.sch]
2017-04-15 Start working on button (#15)
    [backplane.sch]
2017-04-18 Add button footprint and fix some NCs
    Fixes #15
    [backplane.kicad_pcb, backplane.sch]
2017-04-19 Improve and simplify traces
    [backplane.kicad_pcb]
2017-04-19 Update schematics and renderings
    [backplane.kicad_pcb, backplane.sch]
2017-04-20 Add more groundplane vias
    [backplane.kicad_pcb]
2017-04-20 Add protection diode and polyfuse to schematics
    [backplane.sch]
2017-04-20 Protection circuit and re-routing
    This will require a new stencil.
    [backplane.kicad_pcb, backplane.sch]
2017-04-21 Smaller footprints for ADC
    [backplane.kicad_pcb]
2017-04-21 Small cleanup
    [backplane.kicad_pcb]
2017-04-21 Change net names for RX/TX
    [backplane.kicad_pcb, backplane.sch]
2017-04-21 Update renderings and schematics v1.1
    [backplane.sch]
2017-04-23 Add some datasheets
    [backplane.sch]
2017-04-23 Fix DO214 3D model orientation
    [backplane.kicad_pcb]
2017-04-23 Improve some silkscreen labels
    [backplane.kicad_pcb]
2017-04-23 Move up C2 footprint
    [backplane.kicad_pcb]
2017-04-23 Improve trace nearby via
    [backplane.kicad_pcb]
2017-05-06 Fix voltage divisor resistance values
    Previous values were wrong and would saturate the ADC.
    [backplane.sch]
2017-06-02 Testsuite: More fixes, add ADC test
2017-06-16 Add self locking header test board (#17)
    [headertest.kicad_pcb, headertest.sch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]
2017-06-16 Fix button footprint (fixes #18)
    [backplane.kicad_pcb]
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2017-08-10 Update revision
    [backplane.kicad_pcb, backplane.sch]
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2017-10-10 Add iC880A mounting hole (fixes #21)
    [backplane.kicad_pcb]
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2017-10-10 Add PPS pin (fixes #20)
    [backplane.kicad_pcb, backplane.sch]
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2017-10-11 Fix rotation of 3D objects
    [backplane.kicad_pcb]
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2017-11-19 Fix 3D models, update renderings
    [backplane.kicad_pcb]
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2018-01-17 Simplify LEDs (fixes #19)
    Also, make pin 1 dot for SHT21 bigger.
    [backplane.kicad_pcb, backplane.sch]
2018-01-17 Increase restring of MP1584 module (#23)
    [backplane.kicad_pcb]
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2018-01-17 Increase 2x20 pin header restrings (#23)
    Also update LED resistor values
    [backplane.kicad_pcb, backplane.sch]
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2018-01-17 Increase iC880A restrings (#23)
    Also remove dangling trace
    [backplane.kicad_pcb]
2018-01-17 Increase pin header restrings (#23)
    [backplane.kicad_pcb]
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2018-03-26 Update for Zvepower regulator
    It has castellated edges and is slightly smaller.
    [backplane.kicad_pcb, backplane.sch]
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2018-05-09 Add SHTC3 in parallel to SHT21
    [backplane.kicad_pcb, backplane.sch]
2018-05-09 Update version string on PCB
    [backplane.kicad_pcb]
2018-05-09 Move Vin connectors out of the way (#26)
    It should be impossible to short with the USB/Ethernet connectors.
    [backplane.kicad_pcb]
2018-05-09 Center MP1584 silkscreen text
    [backplane.kicad_pcb]
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2018-11-01 Add v2 minor variant
    [backplane.kicad_pcb]
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2019-07-16 Fix some DRC warnings
    - Polygon with SHT cutouts was not perfectly closed
    [backplane.kicad_pcb]
2019-07-16 Silkscreen improvements: SHTC3 dot
    [backplane.kicad_pcb]
2019-07-16 Silkscreen improvements: ADC dot
    [backplane.kicad_pcb]
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2019-07-16 Remove C2
    It was always optional and not required in practice.
    [backplane.kicad_pcb, backplane.sch]
2019-07-16 Fix 3D models
    KiCAD keeps breaking them on every version update...
    [backplane.kicad_pcb]
2019-07-16 Show some more designators on silkscreen, generate v2.1
    [backplane.kicad_pcb]
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
